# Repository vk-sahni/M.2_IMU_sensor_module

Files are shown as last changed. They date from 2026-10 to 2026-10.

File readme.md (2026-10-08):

# M.2 RP2350 IMU Sensor Module

A KiCad hardware design for a compact M.2 Key A sensor module built around the Raspberry Pi RP2350B. The board combines an MPU-9250 motion sensor and a BME280 environmental sensor, with UAV and ArduPilot integration as the intended use case.

> **Project status:** Work in progress. The repository contains KiCad design files only; it does not include firmware or establish plug-and-play ArduPilot compatibility. The current design has outstanding KiCad ERC/DRC violations and is not ready for fabrication or flight use.

## GitHub repository description

> KiCad design for an M.2 Key A RP2350B sensor module featuring an MPU-9250 IMU and BME280, intended for UAV and ArduPilot integration experiments.

## Design overview

- **MCU:** RP2350B
- **IMU:** MPU-9250 (accelerometer, gyroscope, and magnetometer)
- **Environmental sensor:** BME280 (pressure, temperature, and humidity)
- **Memory:** W25Q128JVSIQ QSPI flash and APS6404L PSRAM
- **Removable storage:** MicroSD card socket
- **Host connection:** M.2 Key A edge connector
- **Other interfaces:** USB Type-C, SWD test points, and status LEDs
- **Power:** On-board XC6220 3.3 V regulators

The M.2 connector schematic maps 5 V power and sensor I2C signals, including separate `SDA`/`SCL` and `MPU_SDA`/`MPU_SCL` nets. Check the full schematic and target host pinout before connecting the module; M.2 is a connector format, not a guarantee of electrical or firmware compatibility.

## ArduPilot integration

This is a hardware design intended for UAV sensor and ArduPilot integration experiments. ArduPilot supports sensor communications over protocols such as I2C, SPI, UART, and CAN, but a sensor board still needs a compatible driver/backend, wiring, and configuration. This repository does not contain that firmware integration or demonstrate that an ArduPilot flight controller can detect these sensors through this M.2 connection.

Before attempting integration, verify the M.2 host pinout and voltage levels, determine which controller owns each bus, and confirm that the target ArduPilot firmware supports the required sensors and connection arrangement. See the official [ArduPilot sensor-driver documentation](https://ardupilot.org/dev/docs/code-overview-sensor-drivers.html).

## Repository contents

- `PCIe_Pie.kicad_pro` — KiCad project settings
- `PCIe_Pie.kicad_sch` and the other `*.kicad_sch` files — top-level and hierarchical schematics
- `PCIe_Pie.kicad_pcb` — PCB layout
- `CM4IO.pretty/` — project footprint library
- `CM4IO.3dshapes/` — 3D models used by footprints
- `sym-lib-table`, `fp-lib-table` — KiCad library table configuration

## Open the design

1. Install KiCad.
2. Open `PCIe_Pie.kicad_pro`.
3. Review the complete schematic hierarchy and PCB, including the project-local footprint and 3D model libraries.

## Validation status

KiCad command-line ERC and DRC checks run against the current design reported outstanding violations, including unconnected items. Review and resolve these in KiCad before generating manufacturing files. No fabrication outputs, assembled-board test results, sensor calibration results, or flight-test results are included in this repository.

## Safety

Treat the design as experimental. Verify the schematic, PCB rules, power rails, connector orientation, and signal levels before powering hardware. Bench-test and validate the complete sensor/firmware path before any UAV flight; do not rely on this module as a flight-critical sensor without appropriate testing and failsafes.

## References

- [ArduPilot sensor drivers and supported communication protocols](https://ardupilot.org/dev/docs/code-overview-sensor-drivers.html)
- [MPU-9250 datasheet](https://invensense.tdk.com/wp-content/uploads/2015/02/PS-MPU-9250A-01-v1.1.pdf)

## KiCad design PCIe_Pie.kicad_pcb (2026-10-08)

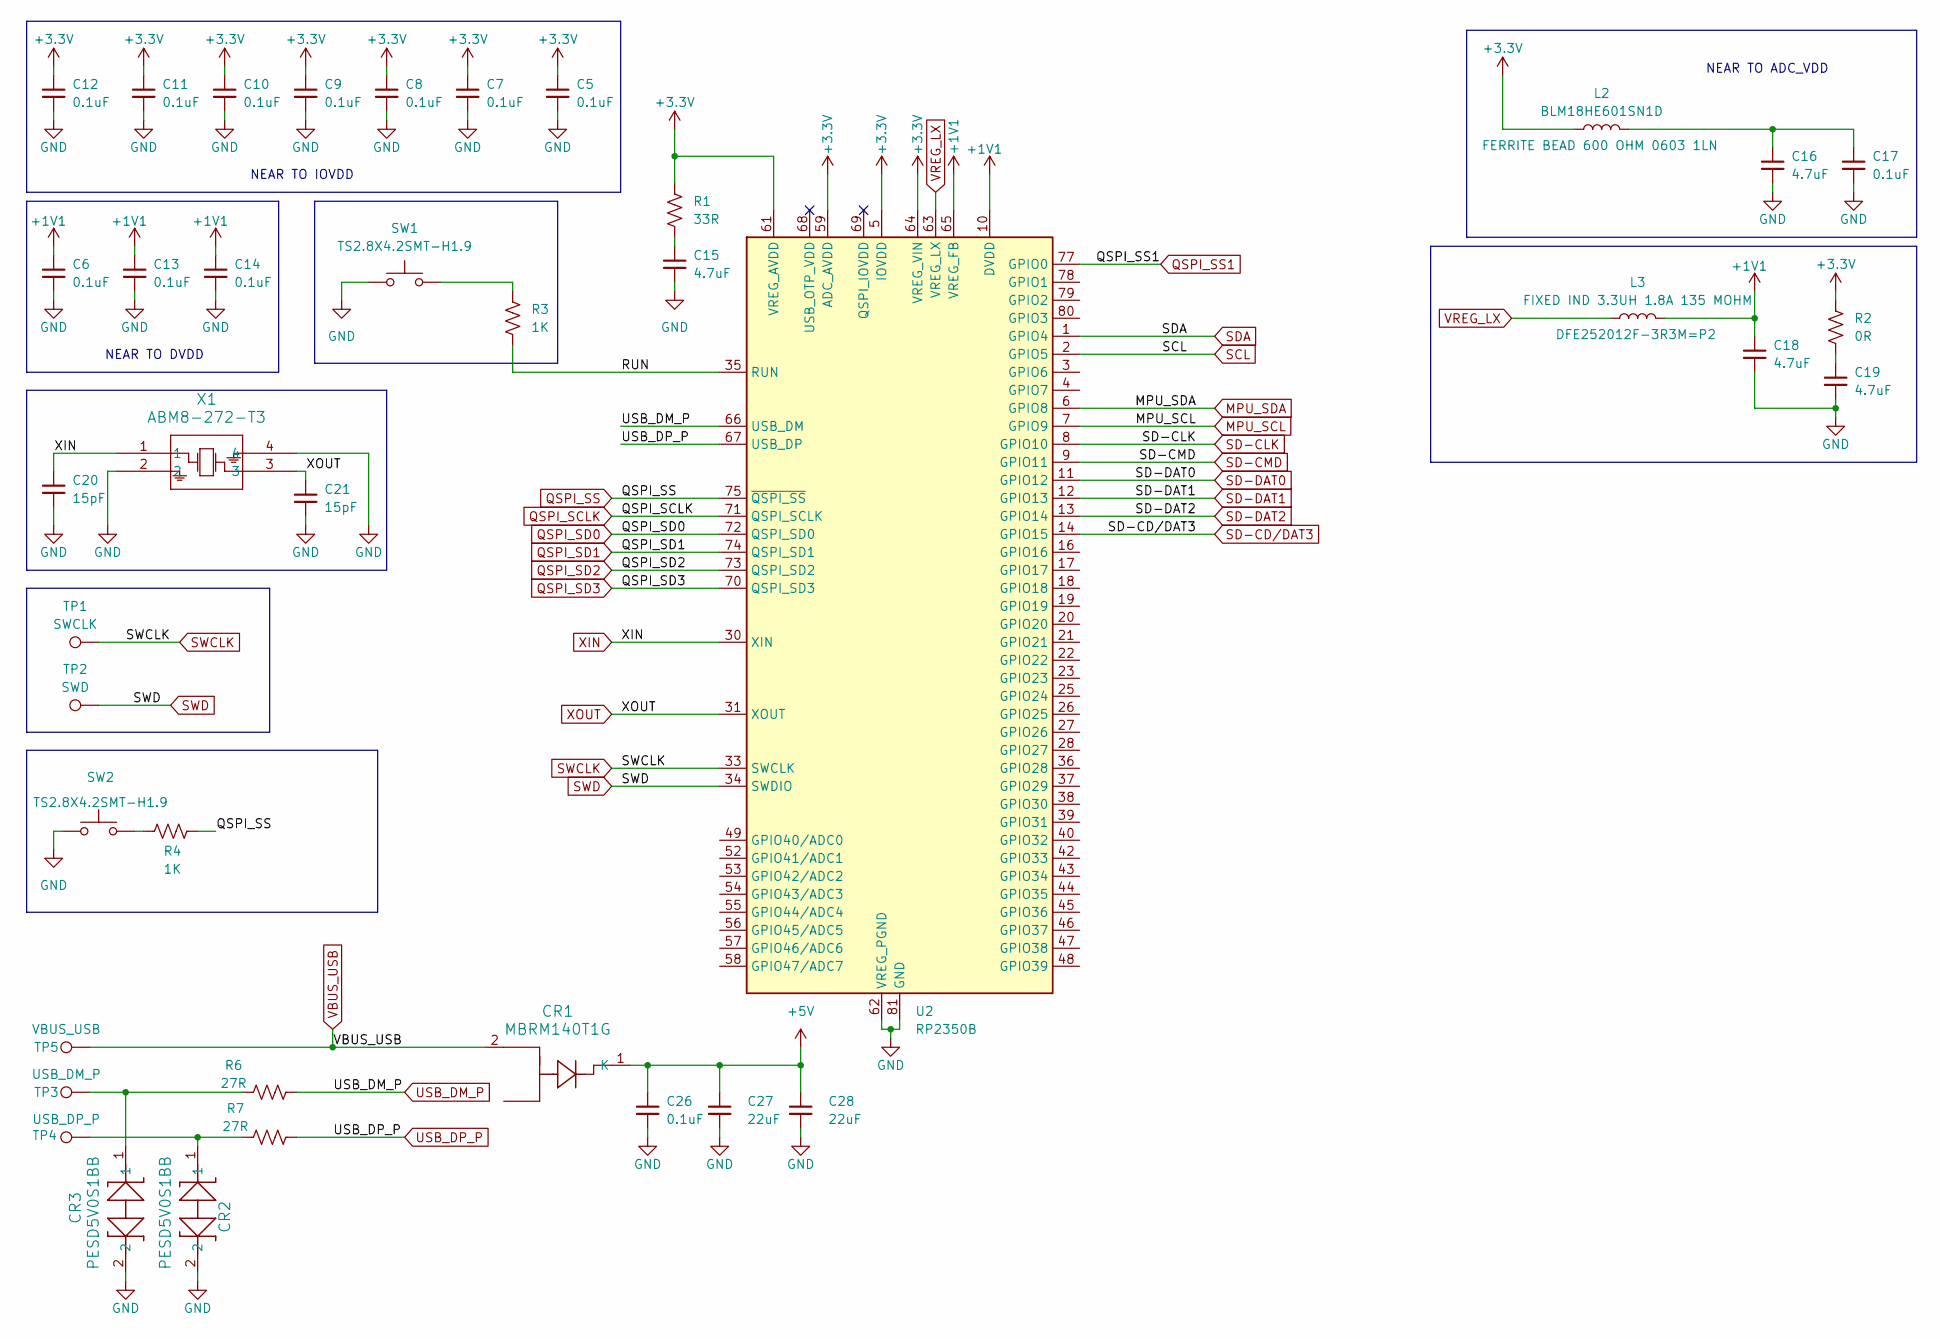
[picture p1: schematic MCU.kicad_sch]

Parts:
C5, C6, C7, C8, C9, C10, C11, C12, C13, C14, C17, C26: 0.1uF; C_0402_1005Metric
C15, C16, C18, C19: 4.7uF; C_0402_1005Metric
C20, C21: 15pF; C_0402_1005Metric
C27, C28: 22uF; C_0402_1005Metric
CR1: MBRM140T1G; CR_POWERMITE_457-04_ONS-L
CR2, CR3: PESD5V0S1BB; SOD523_NXP-L
L2: BLM18HE601SN1D; L_0402_1005Metric; PART FERRITE BEAD 600 OHM 0603 1LN
L3: FIXED IND 3.3UH 1.8A 135 MOHM; L_0402_1005Metric; PART DFE252012F-3R3M=P2
R1: 33R; R_0402_1005Metric
R2: 0R; R_0402_1005Metric
R3, R4: 1K; R_0402_1005Metric
R6, R7: 27R; R_0402_1005Metric
SW1, SW2: TS2.8X4.2SMT-H1.9; SW_Push_SPST_NO_Alps_SKRK
TP1: SWCLK; TestPoint_Pad_1.0x1.0mm
TP2: SWD; TestPoint_Pad_1.0x1.0mm
TP3: USB_DM_P; TestPoint_Pad_1.0x1.0mm
TP4: USB_DP_P; TestPoint_Pad_1.0x1.0mm
TP5: VBUS_USB; TestPoint_Pad_1.0x1.0mm
U2: RP2350B; QFN-80-1EP_10x10mm_P0.4mm_EP3.4x3.4mm
X1: ABM8-272-T3; ABM8-272-T3_ABR

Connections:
+1V1: C6.1, C13.1, C14.1, C18.1, L3.2, U2.10 (DVDD), U2.32 (DVDD), U2.51 (DVDD), U2.65 (VREG_FB)
+3.3V: C5.1, C7.1, C8.1, C9.1, C10.1, C11.1, C12.1, L2.1, R1.1, R2.1, U2.5 (IOVDD), U2.15 (IOVDD), U2.24 (IOVDD), U2.29 (IOVDD), U2.41 (IOVDD), U2.50 (IOVDD), U2.59 (ADC_AVDD), U2.60 (IOVDD), U2.61 (VREG_AVDD), U2.64 (VREG_VIN), U2.76 (IOVDD); also elsewhere on the board
+5V: C26.1, C27.1, C28.1, CR1.1 (K_1); also elsewhere on the board
/MCU/RUN: R3.2, U2.35 (RUN)
GND: C5.2, C6.2, C7.2, C8.2, C9.2, C10.2, C11.2, C12.2, C13.2, C14.2, C15.2, C16.2, C17.2, C18.2, C19.2, C20.2, C21.2, C26.2, C27.2, C28.2, CR2.2, CR3.2, SW1.1, SW2.1, U2.62 (VREG_PGND), U2.81 (GND), X1.2, X1.4; also elsewhere on the board
MPU_SCL: U2.7 (GPIO9); also elsewhere on the board
MPU_SDA: U2.6 (GPIO8); also elsewhere on the board
unnamed: C15.1, R1.2
unnamed: C16.1, C17.1, L2.2
unnamed: C19.1, R2.2
unnamed: CR2.1, R7.1, TP4.1 (1_1)
unnamed: CR3.1, R6.1, TP3.1 (1_1)
unnamed: R3.1, SW1.2
unnamed: R4.1, SW2.2
QSPI_SCLK: U2.71 (QSPI_SCLK); also elsewhere on the board
QSPI_SD0: U2.72 (QSPI_SD0); also elsewhere on the board
QSPI_SD1: U2.74 (QSPI_SD1); also elsewhere on the board
QSPI_SD2: U2.73 (QSPI_SD2); also elsewhere on the board
QSPI_SD3: U2.70 (QSPI_SD3); also elsewhere on the board
QSPI_SS: R4.2, U2.75 (~QSPI_SS); also elsewhere on the board
QSPI_SS1: U2.77 (GPIO0); also elsewhere on the board
SCL: U2.2 (GPIO5); also elsewhere on the board
SD-CD/DAT3: U2.14 (GPIO15); also elsewhere on the board
SD-CLK: U2.8 (GPIO10); also elsewhere on the board
SD-CMD: U2.9 (GPIO11); also elsewhere on the board
SD-DAT0: U2.11 (GPIO12); also elsewhere on the board
SD-DAT1: U2.12 (GPIO13); also elsewhere on the board
SD-DAT2: U2.13 (GPIO14); also elsewhere on the board
SDA: U2.1 (GPIO4); also elsewhere on the board
SWCLK: TP1.1 (1_1), U2.33 (SWCLK)
SWD: TP2.1 (1_1), U2.34 (SWDIO)
USB_DM_P: R6.2, U2.66 (USB_DM); also elsewhere on the board
USB_DP_P: R7.2, U2.67 (USB_DP); also elsewhere on the board
VBUS_USB: CR1.2, TP5.1 (1_1); also elsewhere on the board
VREG_LX: L3.1, U2.63 (VREG_LX)
XIN: C20.1, U2.30 (XIN), X1.1
XOUT: C21.1, U2.31 (XOUT), X1.3

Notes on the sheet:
NEAR TO ADC_VDD
NEAR TO IOVDD
NEAR TO DVDD

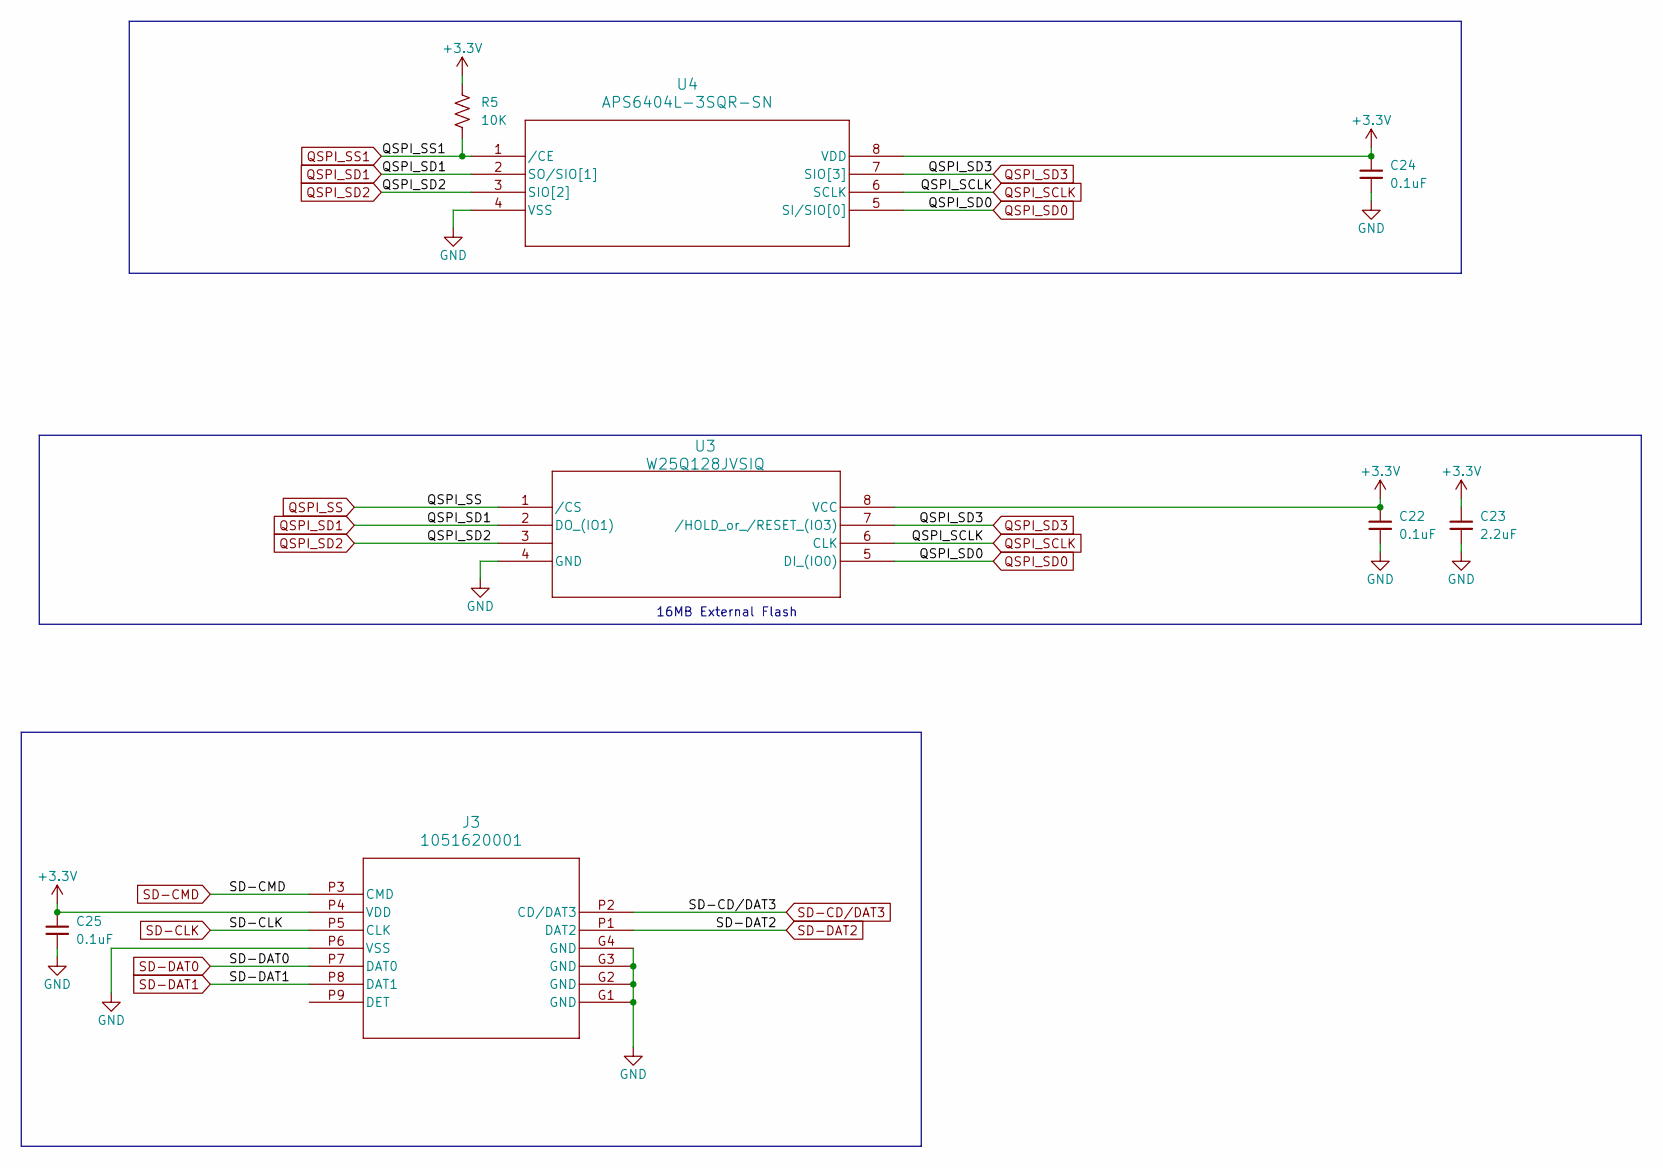
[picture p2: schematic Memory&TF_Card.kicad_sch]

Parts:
C22, C24, C25: 0.1uF; C_0402_1005Metric
C23: 2.2uF; C_0402_1005Metric
J3: 1051620001; 105162-0001_MOL
R5: 10K; R_0402_1005Metric
U3: W25Q128JVSIQ; SOIC_128JVSIQ_WIN-M
U4: APS6404L-3SQR-SN; APS6404L-3SQR-SN_APY-M

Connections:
+3.3V: C22.1, C23.1, C24.1, C25.1, J3.P4 (VDD), R5.1, U3.8 (VCC), U4.8 (VDD); also elsewhere on the board
GND: C22.2, C23.2, C24.2, C25.2, J3.G1 (GND), J3.G2 (GND), J3.G3 (GND), J3.G4 (GND), J3.P6 (VSS), U3.4 (GND), U4.4 (VSS); also elsewhere on the board
QSPI_SCLK: U3.6 (CLK), U4.6 (SCLK); also elsewhere on the board
QSPI_SD0: U3.5 (DI_(IO0)), U4.5 (SI/SIO[0]); also elsewhere on the board
QSPI_SD1: U3.2 (DO_(IO1)), U4.2 (SO/SIO[1]); also elsewhere on the board
QSPI_SD2: U3.3, U4.3 (SIO[2]); also elsewhere on the board
QSPI_SD3: U3.7 (/HOLD_or_/RESET_(IO3)), U4.7 (SIO[3]); also elsewhere on the board
QSPI_SS: U3.1 (/CS); also elsewhere on the board
QSPI_SS1: R5.2, U4.1 (/CE); also elsewhere on the board
SD-CD/DAT3: J3.P2 (CD/DAT3); also elsewhere on the board
SD-CLK: J3.P5 (CLK); also elsewhere on the board
SD-CMD: J3.P3 (CMD); also elsewhere on the board
SD-DAT0: J3.P7 (DAT0); also elsewhere on the board
SD-DAT1: J3.P8 (DAT1); also elsewhere on the board
SD-DAT2: J3.P1 (DAT2); also elsewhere on the board

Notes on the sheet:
16MB External Flash

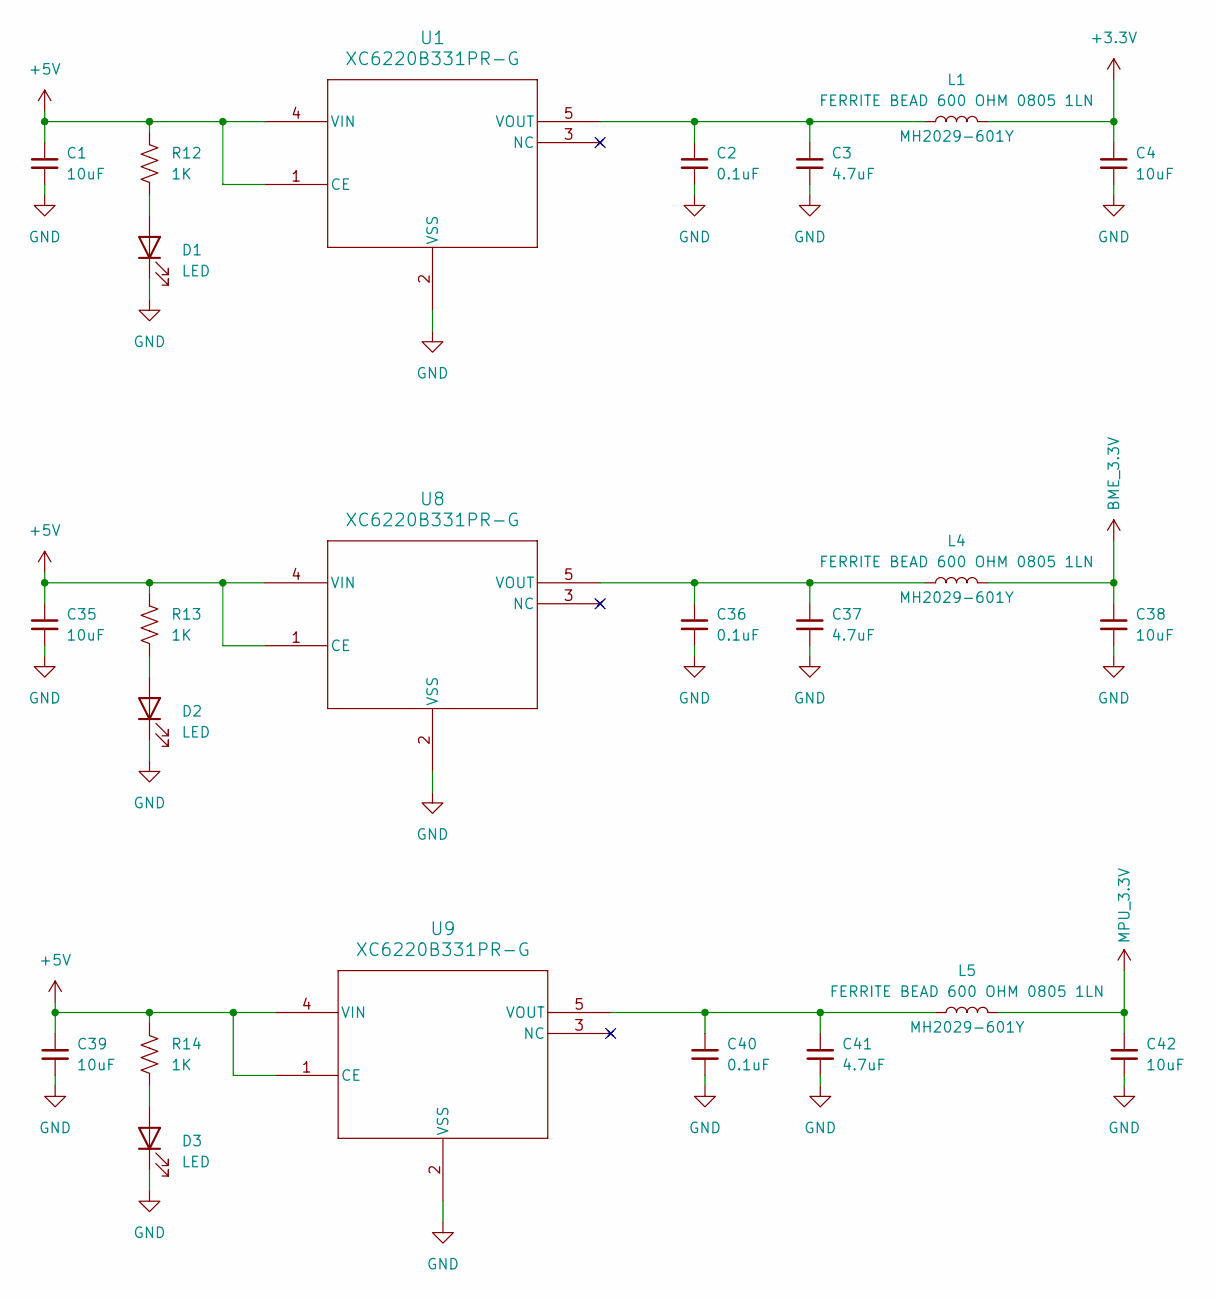
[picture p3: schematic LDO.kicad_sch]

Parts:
C1, C35, C39: 10uF; C_0805_2012Metric
C2, C36, C40: 0.1uF; C_0402_1005Metric
C3, C37, C41: 4.7uF; C_0402_1005Metric
C4, C38, C42: 10uF; C_0402_1005Metric
D1, D2, D3: LED; LED_0402_1005Metric
L1, L4, L5: FERRITE BEAD 600 OHM 0805 1LN; L_0402_1005Metric; Part MH2029-601Y
R12, R13, R14: 1K; R_0402_1005Metric
U1, U8, U9: XC6220B331PR-G; SOT-89-5_TOR

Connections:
+3.3V: C4.1, L1.2; also elsewhere on the board
+5V: C1.1, C35.1, C39.1, R12.1, R13.1, R14.1, U1.1 (CE), U1.4 (VIN), U8.1 (CE), U8.4 (VIN), U9.1 (CE), U9.4 (VIN); also elsewhere on the board
BME_3.3V: C38.1, L4.2; also elsewhere on the board
GND: C1.2, C2.2, C3.2, C4.2, C35.2, C36.2, C37.2, C38.2, C39.2, C40.2, C41.2, C42.2, D1.1 (K), D2.1 (K), D3.1 (K), U1.2 (VSS), U8.2 (VSS), U9.2 (VSS); also elsewhere on the board
MPU_3.3V: C42.1, L5.2; also elsewhere on the board
unnamed: D1.2 (A), R12.2
unnamed: D2.2 (A), R13.2
unnamed: D3.2 (A), R14.2
unnamed: C2.1, C3.1, L1.1, U1.5 (VOUT)
unnamed: C36.1, C37.1, L4.1, U8.5 (VOUT)
unnamed: C40.1, C41.1, L5.1, U9.5 (VOUT)

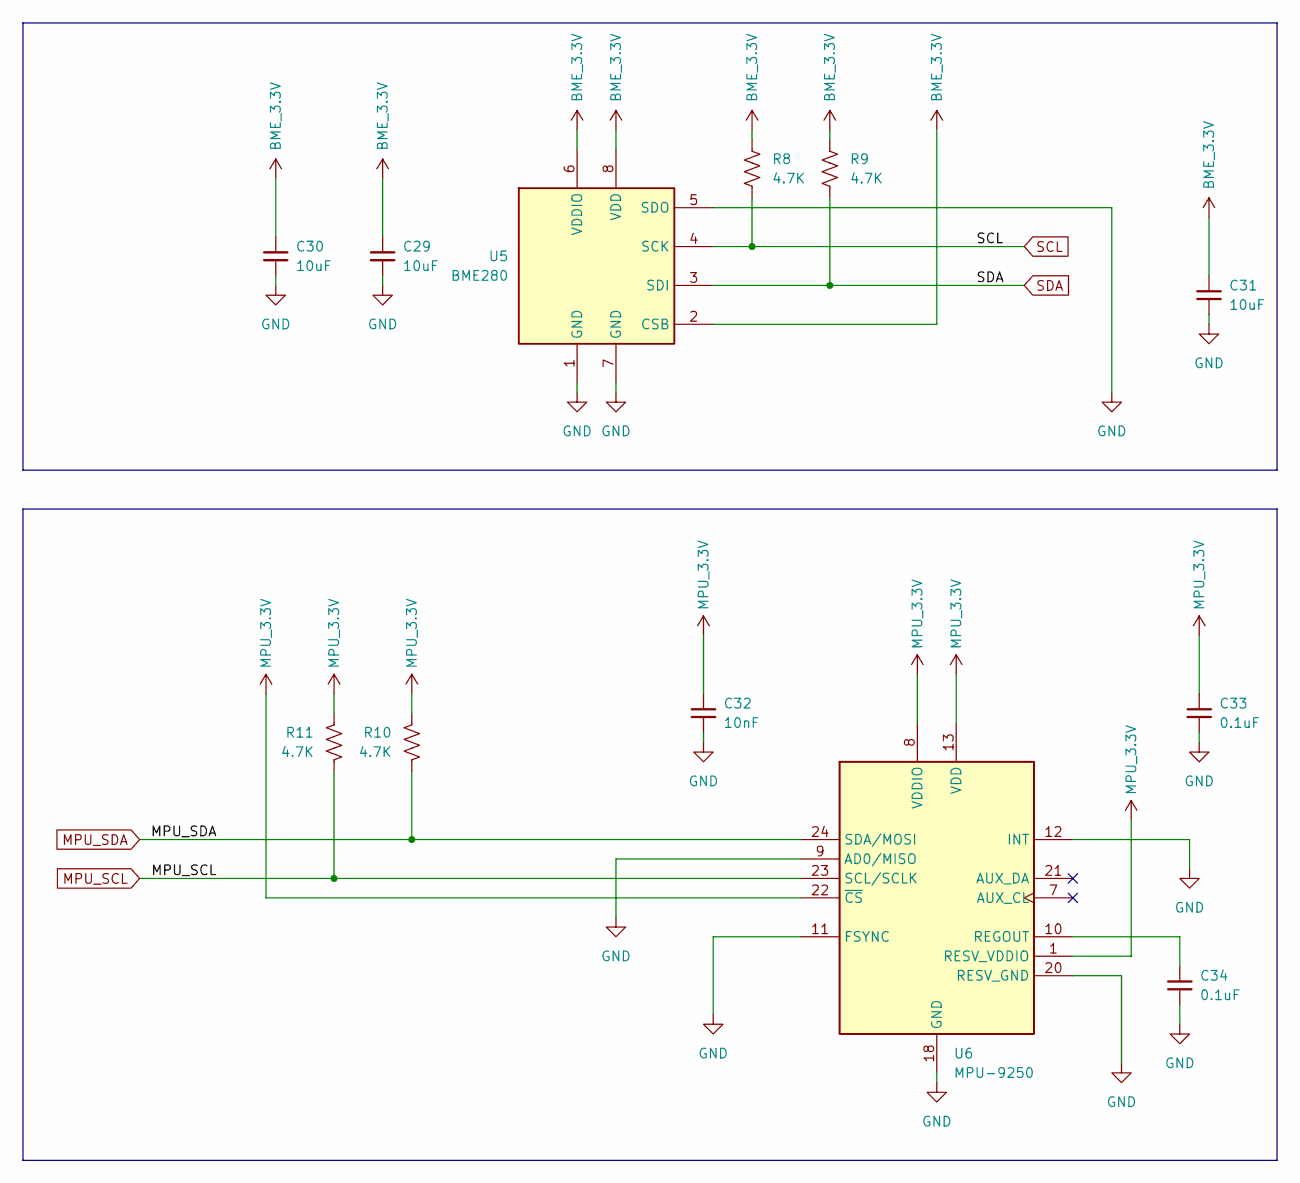
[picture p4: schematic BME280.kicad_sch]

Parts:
C29, C30, C31: 10uF; C_0402_1005Metric
C32: 10nF; C_0402_1005Metric
C33, C34: 0.1uF; C_0402_1005Metric
R8, R9, R10, R11: 4.7K; R_0402_1005Metric
U5: BME280; Bosch_LGA-8_2.5x2.5mm_P0.65mm_ClockwisePinNumbering
U6: MPU-9250; InvenSense_QFN-24_3x3mm_P0.4mm

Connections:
BME_3.3V: C29.1, C30.1, C31.1, R8.1, R9.1, U5.2 (CSB), U5.6 (VDDIO), U5.8 (VDD); also elsewhere on the board
GND: C29.2, C30.2, C31.2, C32.2, C33.2, C34.2, U5.1 (GND), U5.5 (SDO), U5.7 (GND), U6.9 (AD0/MISO), U6.11 (FSYNC), U6.12 (INT), U6.18 (GND), U6.20 (RESV_GND); also elsewhere on the board
MPU_3.3V: C32.1, C33.1, R10.1, R11.1, U6.1 (RESV_VDDIO), U6.8 (VDDIO), U6.13 (VDD), U6.22 (~CS); also elsewhere on the board
MPU_SCL: R11.2, U6.23 (SCL/SCLK); also elsewhere on the board
MPU_SDA: R10.2, U6.24 (SDA/MOSI); also elsewhere on the board
unnamed: C34.1, U6.10 (REGOUT)
SCL: R8.2, U5.4 (SCK); also elsewhere on the board
SDA: R9.2, U5.3 (SDI); also elsewhere on the board

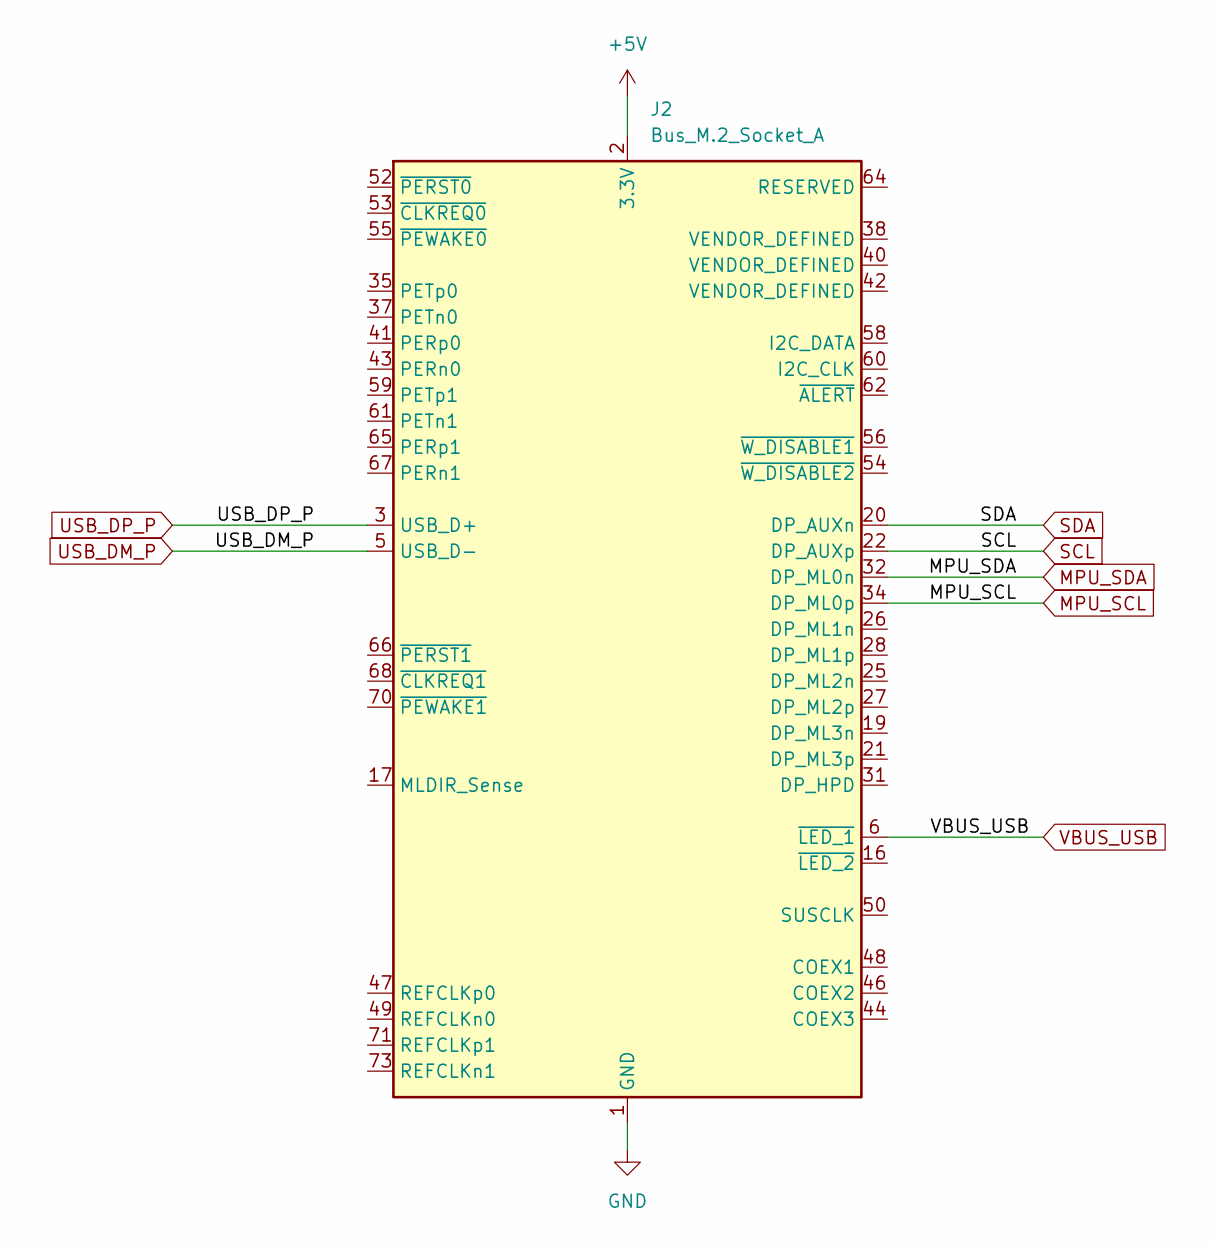
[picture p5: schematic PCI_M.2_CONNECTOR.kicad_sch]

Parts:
J2: Bus_M.2_Socket_A; M.2_3030-xx-A

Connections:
+5V: J2.2 (3.3V), J2.4 (3.3V), J2.72 (3.3V), J2.74 (3.3V); also elsewhere on the board
GND: J2.1 (GND), J2.7 (GND), J2.18 (GND), J2.23 (GND), J2.24 (GND), J2.29 (GND), J2.30 (GND), J2.33 (GND), J2.36 (GND), J2.39 (GND), J2.45 (GND), J2.51 (GND), J2.57 (GND), J2.63 (GND), J2.69 (GND), J2.75 (GND); also elsewhere on the board
MPU_SCL: J2.34 (DP_ML0p); also elsewhere on the board
MPU_SDA: J2.32 (DP_ML0n); also elsewhere on the board
SCL: J2.22 (DP_AUXp); also elsewhere on the board
SDA: J2.20 (DP_AUXn); also elsewhere on the board
USB_DM_P: J2.5 (USB_D-); also elsewhere on the board
USB_DP_P: J2.3 (USB_D+); also elsewhere on the board
VBUS_USB: J2.6 (~LED_1); also elsewhere on the board

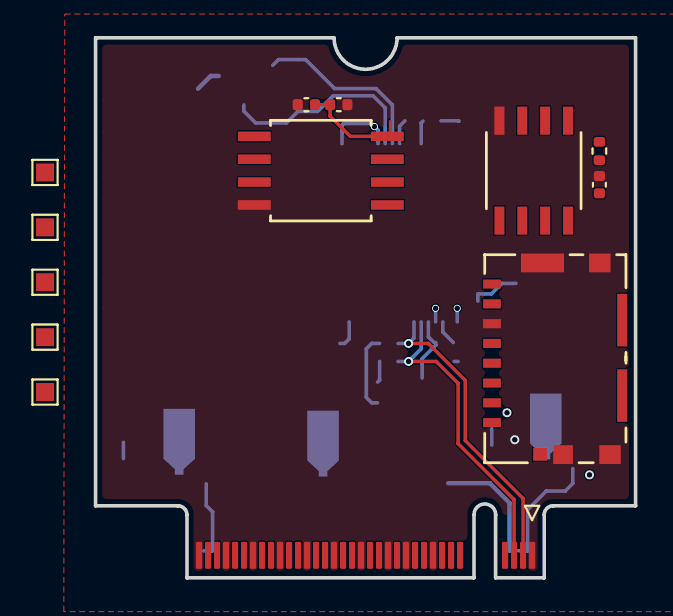
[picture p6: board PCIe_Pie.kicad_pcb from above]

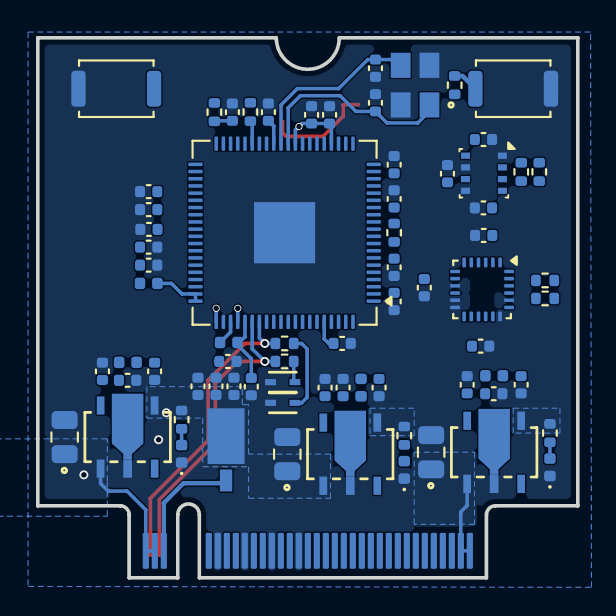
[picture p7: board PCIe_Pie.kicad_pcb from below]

Board: 4 copper layers, 30.0 x 30.0 mm, 85 parts (72 on the bottom side), 46 nets.
